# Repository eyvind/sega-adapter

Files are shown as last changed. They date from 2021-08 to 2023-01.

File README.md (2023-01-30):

# Sega Mega Drive (Genesis) controller to Atari 8-bit adapter

Adapt a Sega Mega Drive controller to the 9-pin Atari joystick standard
using a Microchip PIC 16F1847 microcontroller.

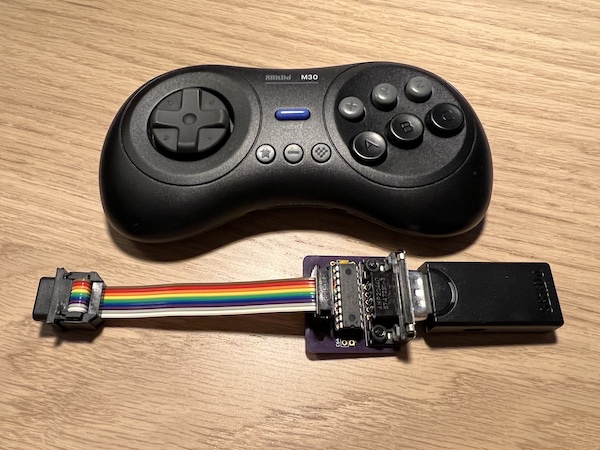
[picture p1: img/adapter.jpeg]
An 8BitDo M30 controller above an uncased circuit board populated with an 18-pin chip, a capacitor, a male DE-9 socket, and an IDC-connected ribbon cable terminated by a female DE-9 plug. An 8BitDo Retro receiver is plugged in to the adapter


This adapter is compatible with [most
computers](#computer-compatibility) that use the Atari 9-pin joystick
connector, supporting most of the features of [Sega Mega Drive
controllers](#controller-compatibility), which use the same connector
with a slightly different pinout.  The Mega Drive was known as Genesis
in the US.

Read all you need to?  [Here's how to build the adapter](#build).

## Features of this adapter

The adapter uses a microcontroller to talk to the Mega Drive controller
and map its four buttons to the three inputs available on an 8-bit
Atari.

The B button on the controller is mapped to the normal joystick button.
Buttons A and C are connected to pins 5 and 9 on the joystick port;
these can be read as extra joystick buttons by the computer.  Most games
that only support one extra button use the C button (pin 9).

### "A is Up" toggle

The start button has no natural mapping since the Atari can only read
three buttons, but a common complaint in platform games on the Atari
(and later the Amiga) was that they often used joystick Up to jump
because of the lack of extra joystick buttons.

A dedicated Up button would solve this problem, but the Start button is
not usually in a good location to be used as a jump button.  The adapter
therefore supports this feature indirectly: holding the Start button
down for a second maps the A button to Up.

Since the joystick button often starts games, a short press of the Start
button is mapped to joystick button 1.  This allows Start to both serve
its normal function (in supported games) and switch the A button between
modes.

### SNACK enhanced mode

[SNACK](https://abbuc.de/produkt/snack-adapter/) is an Atari adapter for
SNES controllers.  It has an enhanced mode that allows all of the
buttons to be read by the Atari, and this adapter supports that mode if
you have a six-button controller.

To switch to SNACK mode on a Sega controller, press Mode, Start, and C
(the right shoulder button if you're using an 8BitDo M30 controller) at
the same time.  Mode+Start+Z (left shoulder on the M30) goes back to
normal mode.

If you're using an 8BitDo Retro Receiver with an Xbox or PlayStation
controller, the button layout is different.  Press Mode+Start+X (left
shoulder) to switch to SNACK mode on these controllers, and Mode+Start+Z
(right shoulder) to go back to normal mode.

The SNES controller has four main buttons: A, B, X, and Y; left and
right shoulder buttons; and START and SELECT.

The main buttons have the same labels and approximately the same diamond
configuration as the A, B, X, and Y buttons on a Mega Drive controller,
but the AB and XY buttons are swapped.

The Mega Drive controller does not have shoulder buttons, so the Z and C
buttons are used instead.  As noted above, the 8BitDo Retro Receiver
maps Z and C to the shoulder buttons on the M30 controller.

Finally, the Mode button stands in for SELECT.

#### Notes

- SNACK mode uses the joystick ports in a completely different way to a
  normal joystick and will produce unexpected results in software that
  is not written to detect it.
- The buttons are not completely independent.  Only one of START, SELECT
  (Mode), X, and Y can be detected at any time, and any of those buttons
  will override A and B.  However, A and B are independent of each
  other, and the shoulder buttons are entirely independent.
- Centering the joystick relies on fairly precise timing to charge the
  Atari's pot capacitors to a specific range, so different computers and
  even cable lengths may make the joystick appear to be intermittently
  leaning in one direction.
- This feature is still experimental.

### Autodetection (Atari 8-bit machines only)

Because of the way the paddle circuits are used to read the second and
third button inputs, 8-bit Ataris read an unconnected second or third
button input as if the button is being held down.

This allows\* games running on the computer to detect the presence of a
multibutton controller by assuming that a button does not exist until it
has been seen to be released.  The adapter supports this autodetection
by leaving its button outputs open unless a Mega Drive controller is
detected or the corresponding button input is pulled low.

To activate the second button when a Mega Drive controller is not
connected, pin 9 on the controller input must be pulled low before the
adapter starts driving the second button output.  This means that the
second button must be pressed once before it can be detected by the
computer.

The third button output is open unless a Mega Drive controller is
detected since there is no other source for a third button input.

\* The astute reader will note that games are _required_ to ignore
button inputs until the button is released, otherwise a nonexistent
button will appear to be continually held down.

## Computer compatibility
### 8-bit Atari computers

The adapter has mostly been tested on 8-bit Ataris using
[Joy2B+](https://github.com/ascrnet/Joy2Bplus) enhanced games.

### 8-bit Commodore computers

The C64, C128, and VIC-20 can also read the second and third buttons.
The extra buttons on these machines are active high, which is opposite
to Atari and Sega.

Pulling the /C64 pin (number 4) on the PIC low inverts the outputs for
the extra buttons, allowing them to be read correctly by the 8-bit
Commodores.  The simplest way to do this is to install a jumper in the
appropriate location on the circuit board.

Because the joystick inputs of the 8-bit Commodores are somewhat
sensitive, all of the pins are normally open (floating).  The extra
button pins are pulled high when active, all other signals are pulled
low when active.

### Amiga

Unlike the 8-bit Commodores the extra buttons on the Amiga are active
low, and unlike all the 8-bit computers they are digital inputs instead
of repurposed paddle circuits.  The Atari mode supports both Atari and
Amiga by driving the pins for buttons two and three both high and low.

### Atari ST (untested)

Button two registers as the second mouse button / port 1 joystick button
if the adapter is plugged into port 0.  The ST does not support
additional joystick buttons on port 1.

## Controller compatibility
### Sega controllers

The adapter is compatible with three- and six-button Mega Drive
controllers. On six-button controllers, buttons X, Y, and Z act as
autofire versions of A, B, and C, while the Mode button is only used for
[SNACK enhanced mode](#snack-enhanced-mode).

Sega Master System controllers are theoretically supported, including
the second button, but this is untested.

### 8BitDo Retro Receiver

The adapter is extensively tested with the [8BitDo Retro Receiver for
SEGA](https://www.8bitdo.com/retro-receiver-genesis-mega-drive/).  It's
a nifty way to use wireless controllers on old hardware.

### Other joysticks or controllers

A controller or joystick with a second button that is not normally
recognised by 8-bit Atari and Commodore computers _may_ work through the
adapter.

**CAUTION:** the second button must be on pin 9 and _not_ pin 5.  Pin 5
is the power pin, and pulling it low may damage your computer or the
adapter.

Single-button joysticks will work but derive no benefit from using the
adapter.

### Atari 7800 controller, Commodore multi-button joysticks, paddles, steering wheels, etc.

These devices will not work and should not be plugged in to the adapter.

## Build

The schematics and parts list for the adapter are in the [kicad
directory](kicad).  If you don't already have a preferred way to
manufacture a PCB, you can order a set of three from [OSH
Park](https://oshpark.com/shared_projects/Nn84QTsl).  You also need a
way to [program the microcontroller](#program).

## Program

[JOY-2-PIC](https://ataribits.weebly.com/joy2pic.html) can program a PIC
using an Atari 8-bit computer's joystick port.  Boot from the .atr image
attached to each release to start programming.  If you have a USB PIC
programmer connected to a PC, use the .hex file instead.

## Modify

If you want to modify the firmware, you need the [xc8
compiler](https://www.microchipdeveloper.com/xc8:installation) from
Microchip to build it.  Run `rake` or `xc8-cc -mcpu=16f1847 -o
sega-adapter.hex *.c` to create a .hex file suitable for a PIC
programmer.

## Rationale

All right, it's time for some history.

- In 1977, Atari released the 2600 game console.
- In 1981, Commodore released the VIC-20 home computer.
- In 1984, Sega released the SG-1000 II console with one main
  improvement from the SG-1000: detachable controllers.

These machines all used the same physical connector with an almost
identical pinout for their controllers, and their manufacturers stuck
with the standard through later generations, tempting people to swap
controllers and joysticks between the systems.

Most of the time, this more or less worked.  Buttons were not always
completely compatible, but most Atari and Commodore games only supported
one button so it didn't really matter as long as one button worked.  One
important caveat: Sega chose to put power on pin 5 instead of pin 7, so
mixing and matching had the potential to cause damage to both machines
and controllers.

Initially each signal was carried by an individual pin: four pins for
directions, one for the button, two pins reserved for power and ground,
leaving two pins free for other functions.

### Mega Drive (Genesis)

For the Mega Drive, released in 1988, Sega wanted to have more buttons
(four) than there were available pins on the controller port (three).
They solved this problem by using one pin (7) as an output from the
console to the controller, allowing two pins (6 and 9) to multiplex the
A, B, C, and Start buttons.

### Joy2B+

Fast forward 20 years, to January 2019.  A poster on an [Atari 8-bit
forum](https://atariage.com/forums/topic/278884-2-button-joystick/?do=findComment&comment=4206381)
introduced a design for a three-button joystick for the 8-bit Ataris,
and -- crucially -- included patched versions of existing games that
supported the extra buttons.  This was the
[Joy2B+](https://github.com/ascrnet/Joy2Bplus) project.

Suddenly, there was a reason to connect a joystick with more than one
button to an Atari.

### 8BitDo Retro Receiver for SEGA

Finally, a month later, a Hong Kong-based company called 8BitDo released
a device that allowed Bluetooth game controllers to be used with Sega
consoles, the [8BitDo Retro Receiver for
SEGA](https://www.8bitdo.com/retro-receiver-genesis-mega-drive/)...
tantalisingly close to being compatible with Atari joystick ports.

## Pinout

```
                      PIC 16F1847
                     +---------_---------+
                     |                   |
            Atari 5 -|  1  RA2   RA1  18 |- Atari 1
                     |                   |
            Atari 6 -|  2  RA3   RA0  17 |- Atari 2
                     |                   |
            Atari 9 -|  3  RA4   RA7  16 |- Atari 3
                ___  |                   |
                C64 -|  4  RA5   RA6  15 |- Atari 4
                     |                   |
    Atari 8  SEGA 8 -|  5  GND   +5v  14 |- Atari 7  SEGA 5
                     |                   |
             SEGA 1 -|  6  RB0   RB7  13 |- SEGA 6
                     |                   |
             SEGA 2 -|  7  RB1   RB6  12 |- SEGA 7
                     |                   |
             SEGA 3 -|  8  RB2   RB5  11 |- SEGA 9
                     |                   |
             SEGA 4 -|  9  RB3   RB4  10 |- X
                     |                   |
                     +-------------------+
```

## Acknowledgements

Information on reading Sega controllers came from
https://github.com/jonthysell/SegaController/wiki/How-To-Read-Sega-Controllers
and
https://www.raspberryfield.life/2019/03/25/sega-mega-drive-genesis-6-button-xyz-controller/

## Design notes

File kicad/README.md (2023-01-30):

# KiCad schematic

This PCB features a detachable ribbon cable to connect it to the
computer and an optional jumper to switch the adapter to C64 mode.

PCBs can be ordered in sets of three from [OSH
Park](https://oshpark.com/shared_projects/Nn84QTsl), or any other PCB
manufacturer that accepts KiCad schematics.

The previously available alternative versions of the PCB have been
removed for simplicity.  They can still be found in git history.

DigiKey part numbers are provided as a convenience but alternative
parts can certainly be used.

## BOM

| Component | DigiKey part number |
| --- | --- |
| PIC 16F1874 microcontroller | PIC16F1847-I/P-ND |
| 0.1uF capacitor | 1109PHCT-ND |
| 18-pin socket | ED3018-ND |
| D-sub male socket | A32088-ND |
| IDC header | S2011EC-05-ND |
| D-sub female plug with ribbon cable | H7FXH-0906G-ND |
| IDC connector | LKR10H-ND |
| Jumper header (optional) | S2011EC-01-ND |
| Jumper (optional) | S9001-ND |

### Optional jumper

The jumper is used to switch the adapter between Atari and C64 mode.  If
the adapter is only going to be used with one kind of computer, the
jumper and its header can either be omitted entirely (Atari/Amiga) or
replaced with a solder bridge or wire (C64/VIC-20).

### Optional joystick pigtail

Instead of using the IDC header and ribbon cable, a joystick pigtail can
be soldered directly to the board.  Any cable from an old joystick or
half of a joystick extension cable can be used for a pigtail, as long as
it has nine wires.

## Assembly notes

- The ribbon cable is 2m long, so it is a good idea to cut it to a more
  reasonable length.  The remaining cable can be used with standalone
  d-sub connectors (part number HHFP09H-ND) to make more adapters.

- When attaching the IDC connector to the ribbon cable, make sure that
  pin 1 is flush against the side and that there is a small gap on the
  other side.  This is because the connector has ten pins while the
  cable only has nine.

- Make sure that pin 1 of the cable is on the same side as pin 1 of the
  header when connecting the cable to the board.  Pin 1 is the one with
  the square pad on the circuit board.

- If you are using alternative parts, please note that there isn't much
  clearance between the IC socket and the IDC header.  Depending on the
  socket used, a shrouded IDC header may not fit.

## Licence

The schematics for this project are licensed under the [Creative Commons
Attribution 4.0
International](https://creativecommons.org/licenses/by/4.0/) licence.
See [LICENSE](LICENSE) for details.

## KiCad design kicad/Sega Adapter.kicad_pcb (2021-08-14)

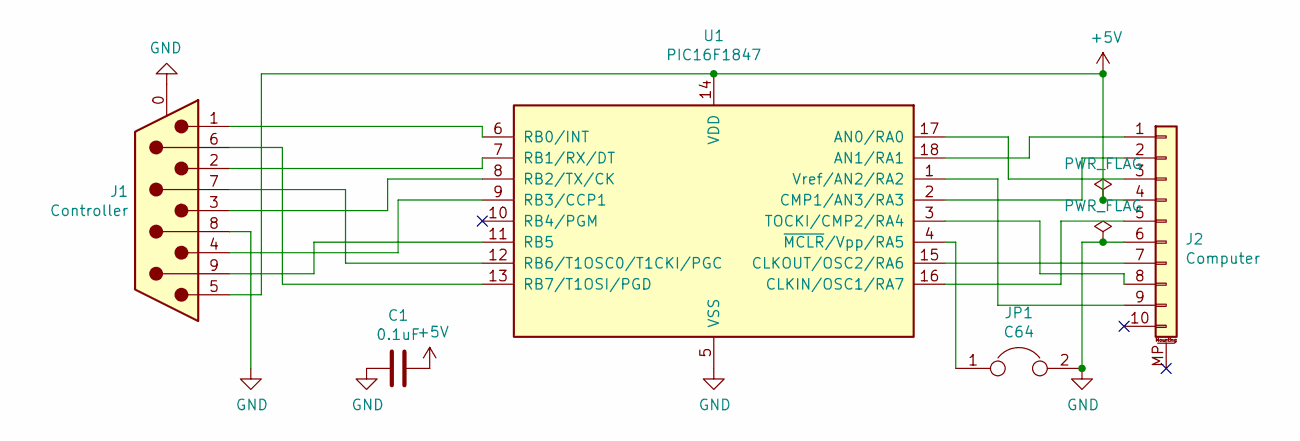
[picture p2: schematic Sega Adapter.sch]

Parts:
C1: 0.1uF; C_Axial_L3.8mm_D2.6mm_P7.50mm_Horizontal
J1: Controller; DSUB-9_Male_Horizontal_P2.77x2.84mm_EdgePinOffset7.70mm_Hou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
J2: Computer; PinHeader_2x05_P2.54mm_Vertical
JP1: C64; PinHeader_1x02_P2.54mm_Vertical
U1: PIC16F1847; DIP-18_W7.62mm

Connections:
+5V: C1.2, J1.5, J2.4, U1.14 (VDD)
GND: C1.1, J1.0 (PAD), J1.8, J2.6, JP1.2, U1.5 (VSS)
unnamed: J1.1, U1.6 (RB0/INT)
unnamed: J1.2, U1.7 (RB1/RX/DT)
unnamed: J1.3, U1.8 (RB2/TX/CK)
unnamed: J1.4, U1.9 (RB3/CCP1)
unnamed: J1.6, U1.13 (RB7/T1OSI/PGD)
unnamed: J1.7, U1.12 (RB6/T1OSC0/T1CKI/PGC)
unnamed: J1.9, U1.11 (RB5)
unnamed: J2.1, U1.18 (AN1/RA1)
unnamed: J2.2, U1.2 (CMP1/AN3/RA3)
unnamed: J2.3, U1.17 (AN0/RA0)
unnamed: J2.5, U1.16 (CLKIN/OSC1/RA7)
unnamed: J2.7, U1.15 (CLKOUT/OSC2/RA6)
unnamed: J2.8, U1.3 (TOCKI/CMP2/RA4)
unnamed: J2.9, U1.1 (Vref/AN2/RA2)
unnamed: JP1.1, U1.4 (~MCLR~/Vpp/RA5)

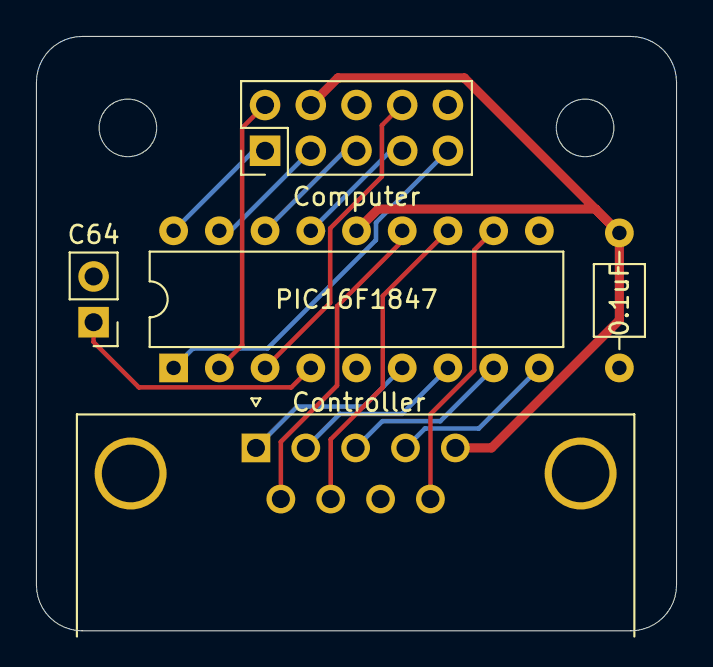
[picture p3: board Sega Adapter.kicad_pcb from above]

Board: 2 copper layers, 35.6 x 33.0 mm, 5 parts (0 on the bottom side), 17 nets.

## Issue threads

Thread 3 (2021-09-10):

Status

TheRobotFactory, 2021-09-10:
Just FYI, I've forked your repo, made a new version of the PCB that I think I can fit in a case (it's a slightly bigger version of your tiny board with a mounting hole in the middle) and i've ordered some from OSH Park.

When they arrive I'll make one, check It works and design a case for it, then I'll send a pull request your way to add the changes back into your project. I don't want to send them over untested.

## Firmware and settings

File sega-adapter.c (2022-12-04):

#include "sega-adapter.h"

void setup_pins(void) {
	OSCCON = OSCCON_16MHZ;

	// Enable weak pull-ups
	OPTION_REG = 0b01111111;

	// PORTA is connected to the computer, PORTB to the controller
	// RA1,0,7,6 are up,down,left,right outputs to the computer
	// RB0,1,2,3 are up,down,left,right inputs from the controller
	// RB6 is the select line output to the controller
	// RB7,5 are button inputs from the controller
	// RA3 is the trigger button output to the computer
	// RA4,2 are button 2,3 outputs to the computer
	// /RA5 selects C64 mode
	// RB4 is unused

	LATA = BUTTON_MASK;
	LATB = SELECT_MASK;

	TRISA = 0b11111111;
	TRISB = (uint8_t) ~SELECT_MASK;

	ANSELA = 0;
	// set PORTB4 as analog to save power
	ANSELB = 0b00010000;
}

int main(void) {
	static controller_t controller;

	setup_pins();
	while (1) {
		controller = read_controller();
		if (controller.SNACK_TIME) {
			for (uint8_t i = 0; i < 4; ++i) {
				write_snack(controller);
				slow_delay(500);
			}
		} else {
			write_joy2b(controller);
			slow_delay(2000);
		}
		CLRWDT();
	}

	return 0;
}

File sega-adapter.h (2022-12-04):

#ifndef SEGA_ADAPTER_H
#define SEGA_ADAPTER_H

#include <xc.h>
#include "controller.h"

#pragma config FOSC = INTOSC	// Oscillator Selection
#pragma config WDTE = ON	// Watchdog Timer Enable
#pragma config PWRTE = OFF	// Power-up Timer Enable
#pragma config MCLRE = OFF	// MCLR Pin Function Select
#pragma config CP = OFF		// Flash Program Memory Code Protection
#pragma config CPD = OFF	// Data Memory Code Protection
#pragma config BOREN = ON	// Brown-out Reset Enable
#pragma config CLKOUTEN = OFF	// Clock Out Enable
#pragma config IESO = ON	// Internal/External Switchover
#pragma config FCMEN = ON	// Fail-Safe Clock Monitor Enable
#pragma config WRT = OFF	// Flash Memory Self-Write Protection
#pragma config PLLEN = OFF	// PLL Enable
#pragma config STVREN = ON	// Stack Overflow/Underflow Reset Enable
#pragma config BORV = LO	// Brown-out Reset Voltage Selection
#pragma config LVP = OFF	// Low-Voltage Programming Enable

const uint8_t OSCCON_16MHZ=0b01111000;
const uint8_t OSCCON_31KHZ=0b00000000;
const unsigned long CLOCK_FACTOR=516;	// 16MHz/31kHz
#define _XTAL_FREQ 31000	// Use n*CLOCK_FACTOR at 16MHz
#define slow_delay(us) OSCCON = OSCCON_31KHZ; __delay_us(us); OSCCON = OSCCON_16MHZ

controller_t read_controller(void);
void write_joy2b(const controller_t controller);
void write_snack(const controller_t controller);

#endif // SEGA_ADAPTER_H

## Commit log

2021-01-21 Correct spelling and add credit where due
    It's "Mega Drive" not "Megadrive." Apparently.
    [sega-adapter.c]
2021-01-21 Add 8-bit Commodore mode
    The second and third joystick buttons are used differently on the 8-bit
    Commodore computers; the potentiometer pins are pulled high instead of
    low when the button is pressed. Add an option to use the adapter with
    these machines.
2021-01-24 Move pins around to put outputs on PORTA
    The high-impedance input mode of the PORTB pins has insufficiently high
    impedance to use as a "low" state for buttons 2 and 3. Shift the pins
    around so that all outputs are on PORTA, where the input mode resistance
    is higher.
    Driving the pins high (for up/down/left/right/fire) or low (for buttons
    two and three) can cause problems for the 8-bit Commodores. Switching
    the signal tristates between input and output instead avoids this.
    [sega-adapter.c, sega-adapter.h]
2021-01-24 Simplify button state logic
    Make a new flag called TWO_BUTTON in the controller state to track if a
    second button is present, simplifying the code that disconnects the
    buttons in Atari mode and allowing it to use the same tristate logic as
    the Commodores.
    Remove the SIX_BUTTON flags since they're not used.
2021-04-25 Add KiCad files for pcb
    [Sega Adapter.kicad_pcb, Sega Adapter.sch]
2021-04-25 Add KiCad projects for two adapter variants
    The full adapter has an ICSP header for programming the PIC, a three-pin
    jumper for C64/programming mode, and through-hole D-sub connectors.
    The compact pcb removes the ICSP header but still has through-hole
    connectors and a jumper for C64 mode.
    The tiny pcb uses solder cup D-sub connectors and has a simple solder
    bridge jumper for C64 mode.
    [Sega Adapter.kicad_pcb, Sega Adapter.sch]
2021-05-09 Get rid of vias
    [Sega Adapter.kicad_pcb]
2021-07-06 Switch compact adapter to IDC connector
    [Sega Adapter.kicad_pcb, Sega Adapter.sch]
2021-07-07 Add README and licence
    Also tweak the PCBs:
    - round the corners of the full PCB
    - add a copyright message to the full and tiny PCBs
    [Sega Adapter.kicad_pcb]
2021-08-14 Hide the J2 label
    [Sega Adapter.kicad_pcb]
2021-08-21 Add BOM and recommend the compact pcb
2021-08-21 Link to the schematics from the project README
2021-08-29 Add six-button support with autofire
    The select line toggle sequence to read the X, Y, Z, and MODE buttons is
    timing sensitive, and is too slow for the 8bitdo receiver with the PIC
    system clock at 500kHz (the default) or 1MHz. At 2MHz, it works.
    Without multiplexing on the computer side there's no way to use the
    extra buttons directly, but autofire is useful. Holding down X, Y, or Z
    respectively pulses the A, B, or C button at around 12Hz.
    [sega-adapter.c, sega-adapter.h]
2022-08-13 Improve six-button compatibility
    Using a non-8bitdo test controller, 2MHz wasn't fast enough to enable
    six-button support. Go all the way to 32MHz (the highest clock speed on
    the 16F1847) to make it work.
2022-08-13 Save power by slowing the clock when idle
    The 32MHz clock requires 4xPLL to be enabled, but switching clocks
    resulted in the top clock speed alternating between 32MHz and 8MHz each
    cycle.
    16MHz seems to be fast enough to satisfy the test controller and does
    not require the 4xPLL.
2022-08-13 Adjust autofire
    Tune the autofire rate to match the 8BitDo adapter's native autofire,
    which is just over 16Hz. Pre-tuning, the rate was around 13Hz.
2022-08-13 Add six-button support to the README file
2022-08-15 Add credit for six-button controller timings
2022-09-17 Add experimental SNACK support
    Hold down the MODE button to switch to SNACK mode.
    SNACK is a project that brings SNES controllers to Atari, and it has a
    "quite clever ;) but also easy to use" mapping for all SNES buttons to
    the Atari.
    The button layout is adapted to the SEGA controller thusly:
    - A and B are swapped
    - X and Y are swapped
    - Z and C are the left and right shoulder buttons, respectively
    - MODE is SELECT
    The 8BitDo M30 controller has shoulder buttons that map to Z and C.
    Link to the SNACK discussion thread on the AtariAge forums:
    https://forums.atariage.com/topic/323171-snack-snes-atari-controler-kit/
    [sega-adapter.c, sega-adapter.h]
2022-09-19 Use SNACK buttons to switch modes
    SNACK uses START+SELECT+left/right shoulder buttons to switch between
    its classic and enhanced modes: when pressed in combination with START
    and SELECT, the right shoulder button switches to enhanced mode and the
    left goes back to classic mode.
    Since SNACK-compatible games may reference this convention, it makes
    sense to use it here.
2022-09-19 Don't toggle A-is-Up in SNACK mode
    The START key is directly useable when the controller is in SNACK mode,
    and A-is-Up is not. Don't hijack the START button when in SNACK mode.
2022-09-23 Run the SNACK cycle more often to smooth timing
    Charging the pot capacitors partway is very timing sensitive. Remove
    conditionals from the code and run a shorter charge twice as often to
    make it less jittery.
    [sega-adapter.c, sega-adapter.h]
2023-01-28 Add Snack support for Xbox/Playstation controllers
    The 8bitdo retro adapter's layout for Xbox/Playstation-style controllers
    needs a different Snack mapping than the Megadrive controller.
    Since the Snack adapter itself uses select/start/shoulder buttons to
    switch between enhanced and normal mode, it makes sense to use the same
    convention for this adapter:
    Start+select+
    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
2023-01-30 Remove the full and tiny pcb variants
    [Sega Adapter.kicad_pcb, Sega Adapter.sch]

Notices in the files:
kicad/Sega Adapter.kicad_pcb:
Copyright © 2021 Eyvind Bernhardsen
